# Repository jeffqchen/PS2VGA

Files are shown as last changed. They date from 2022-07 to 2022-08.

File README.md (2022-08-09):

# PS2VGA

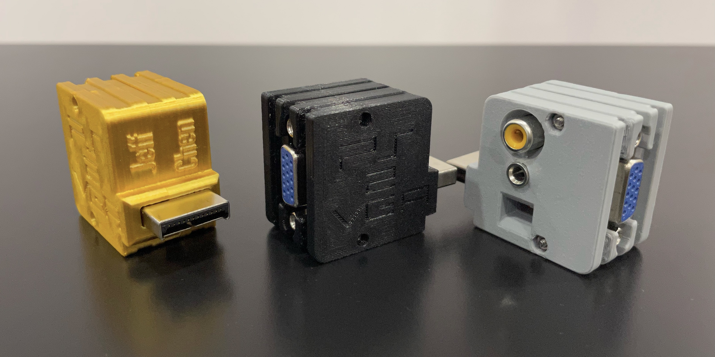
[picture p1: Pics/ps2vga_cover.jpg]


This is an RGB+CSync video and stereo audio analogue output dongle, with a VGA port, a 3.5mm jack and an RCA jack, for the entire PlayStation family. It is a member from my [Console VGA Dongle Series](https://github.com/jeffqchen/Console-VGA-Dongle-Series).

Please refer to the **[Project Wiki](https://github.com/jeffqchen/PS2VGA/wiki)** regarding technical details, parts and building guide.

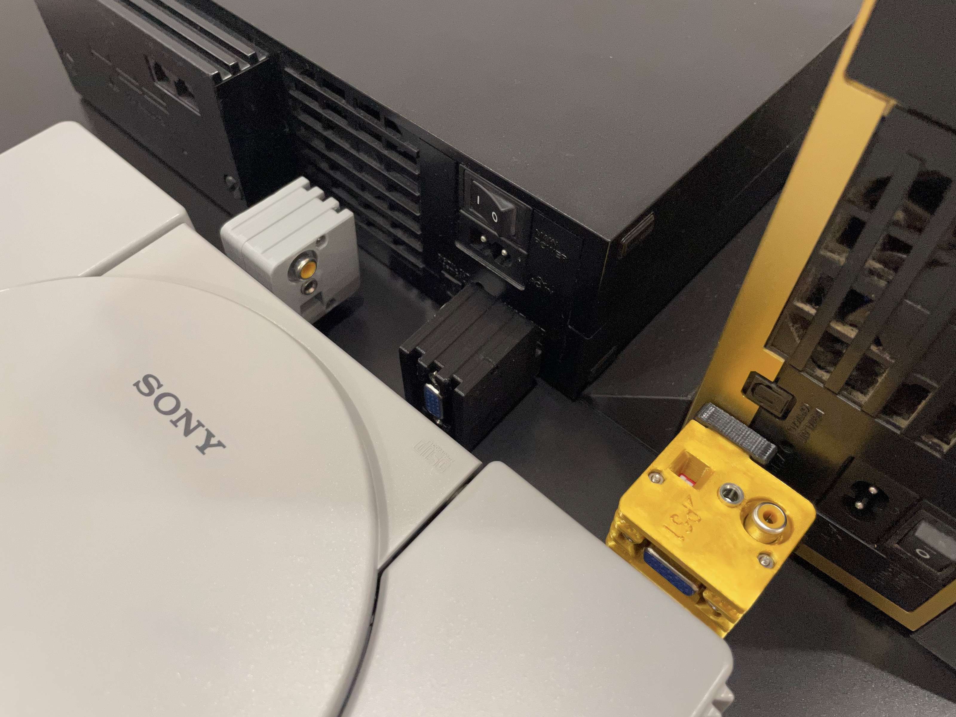
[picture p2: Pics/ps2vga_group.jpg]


---------
## Special Thanks

- Mike Chi of [RetroTINK](https://www.retrotink.com) - [Twitter](https://twitter.com/retrotink2)

- Javier Rodas - [Twitter](https://twitter.com/JaviRodasG)

- Retro Gamer Stuff (Bad_Ad84) - [Twitter](https://twitter.com/RetroGamerStuff)

--------
Shield: [][cc-by-sa]

This work is licensed under a
[Creative Commons Attribution-ShareAlike 4.0 International License][cc-by-sa].

[][cc-by-sa]

[cc-by-sa]: http://creativecommons.org/licenses/by-sa/4.0/
[cc-by-sa-image]: https://licensebuttons.net/l/by-sa/4.0/88x31.png
[cc-by-sa-shield]: https://img.shields.io/badge/License-CC%20BY--SA%204.0-lightgrey.svg

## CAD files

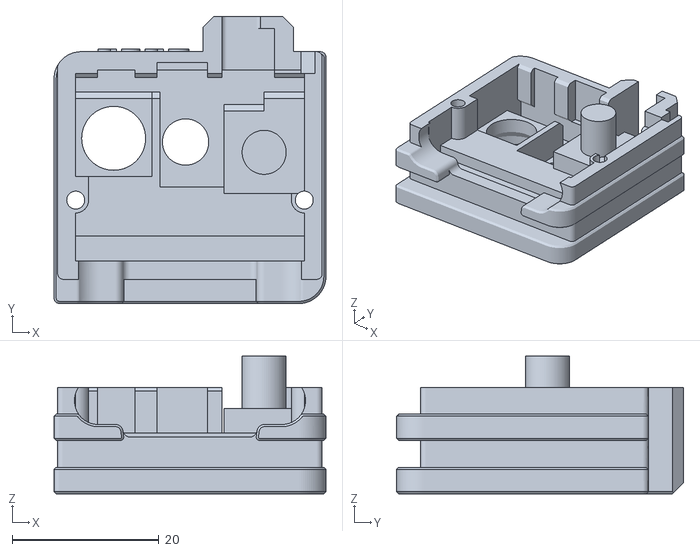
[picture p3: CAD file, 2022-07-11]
3D Print/Shell 2 PS1.stl
37.0 x 39.1 x 18.8

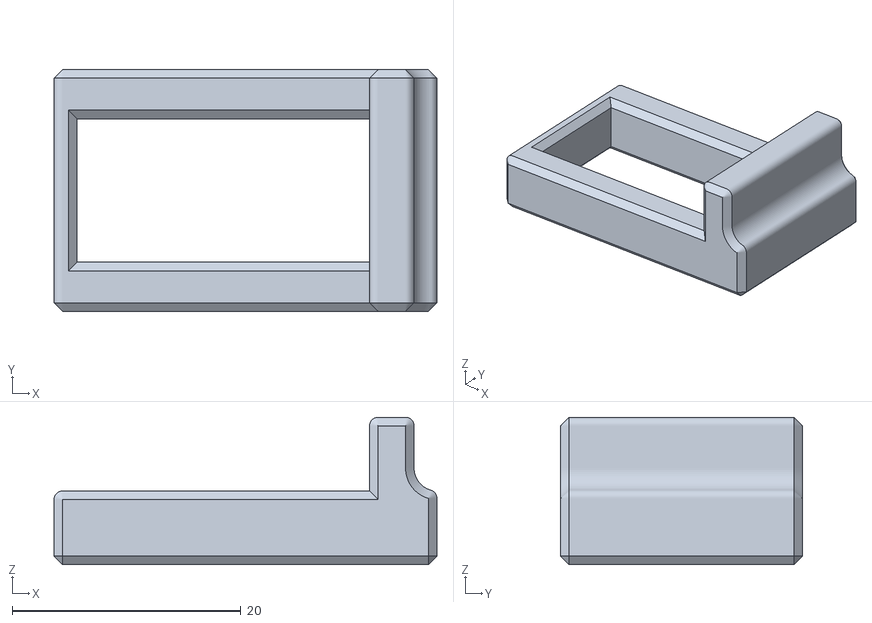
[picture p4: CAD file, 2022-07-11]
3D Print/Vertical Support Ring.stl
33.5 x 21.2 x 12.9

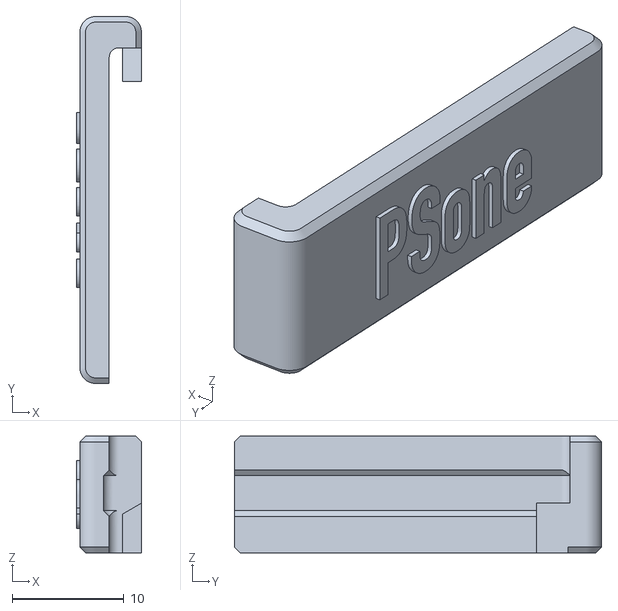
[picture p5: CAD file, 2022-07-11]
3D Print/HA - PSone.stl
5.80 x 32.8 x 10.4

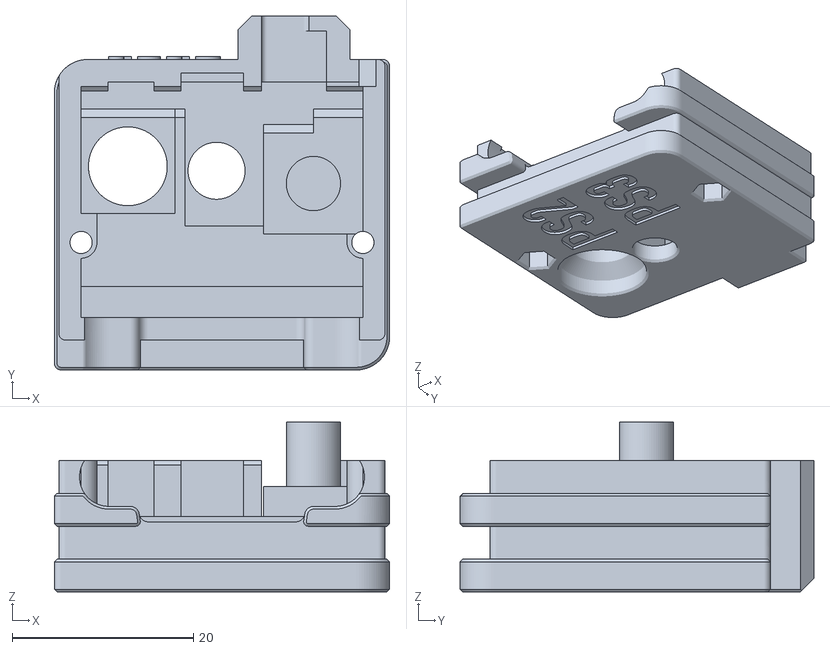
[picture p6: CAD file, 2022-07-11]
3D Print/Shell 2 PS2&3.stl
37.0 x 39.1 x 18.8

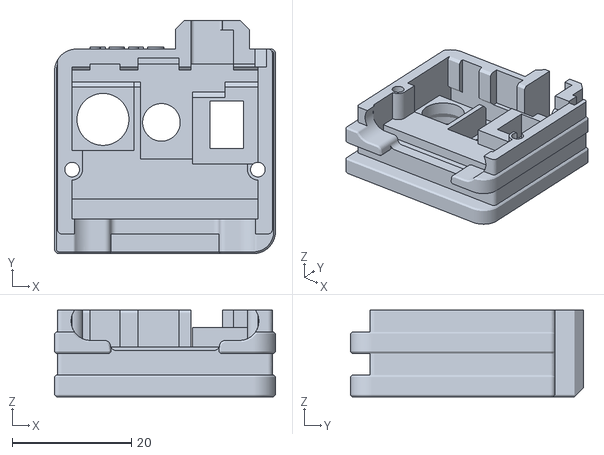
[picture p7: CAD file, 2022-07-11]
3D Print/Shell 2.stl
37.0 x 39.1 x 14.5

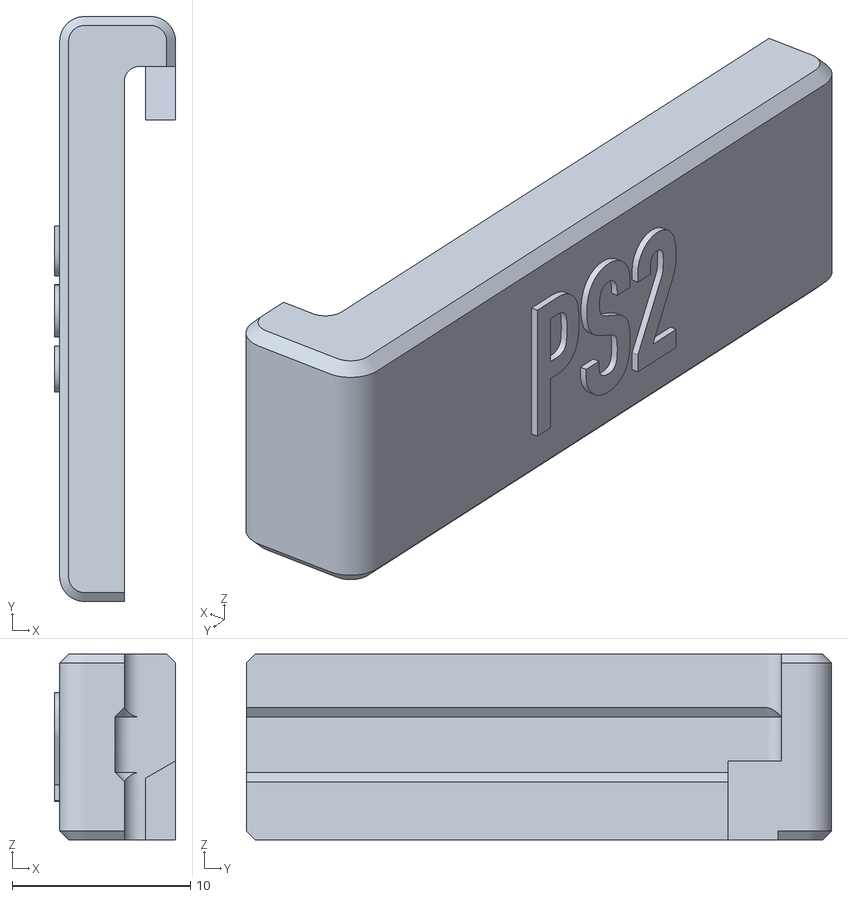
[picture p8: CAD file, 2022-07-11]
3D Print/HA - PS2.stl
6.80 x 32.8 x 10.4

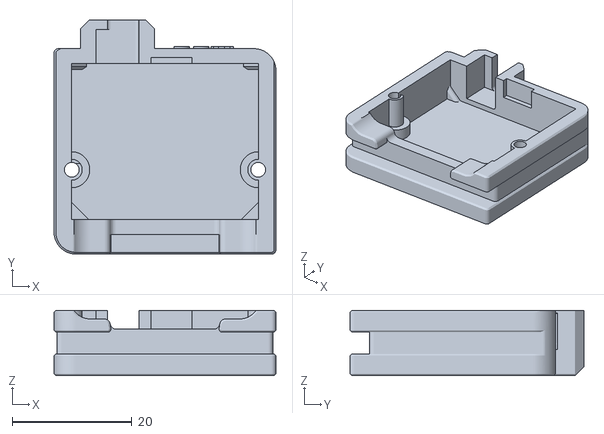
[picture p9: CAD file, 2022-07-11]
3D Print/Shell 1.stl
37.1 x 39.1 x 10.9

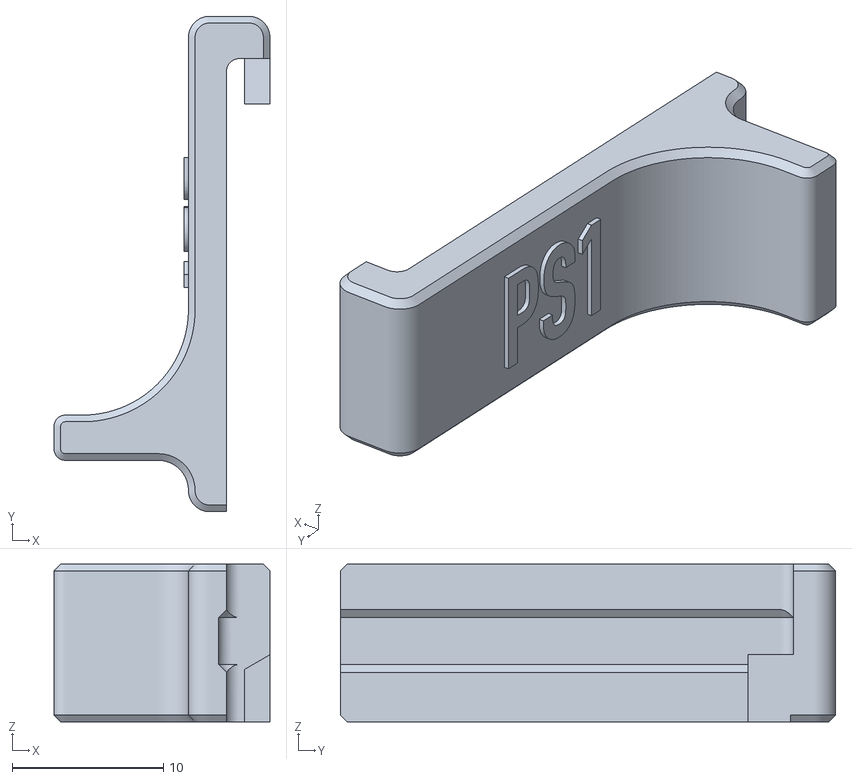
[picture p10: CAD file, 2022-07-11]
3D Print/HA - PS1.stl
14.3 x 32.8 x 10.4

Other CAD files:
3D Print/HA - PS2 Slim 1.stl

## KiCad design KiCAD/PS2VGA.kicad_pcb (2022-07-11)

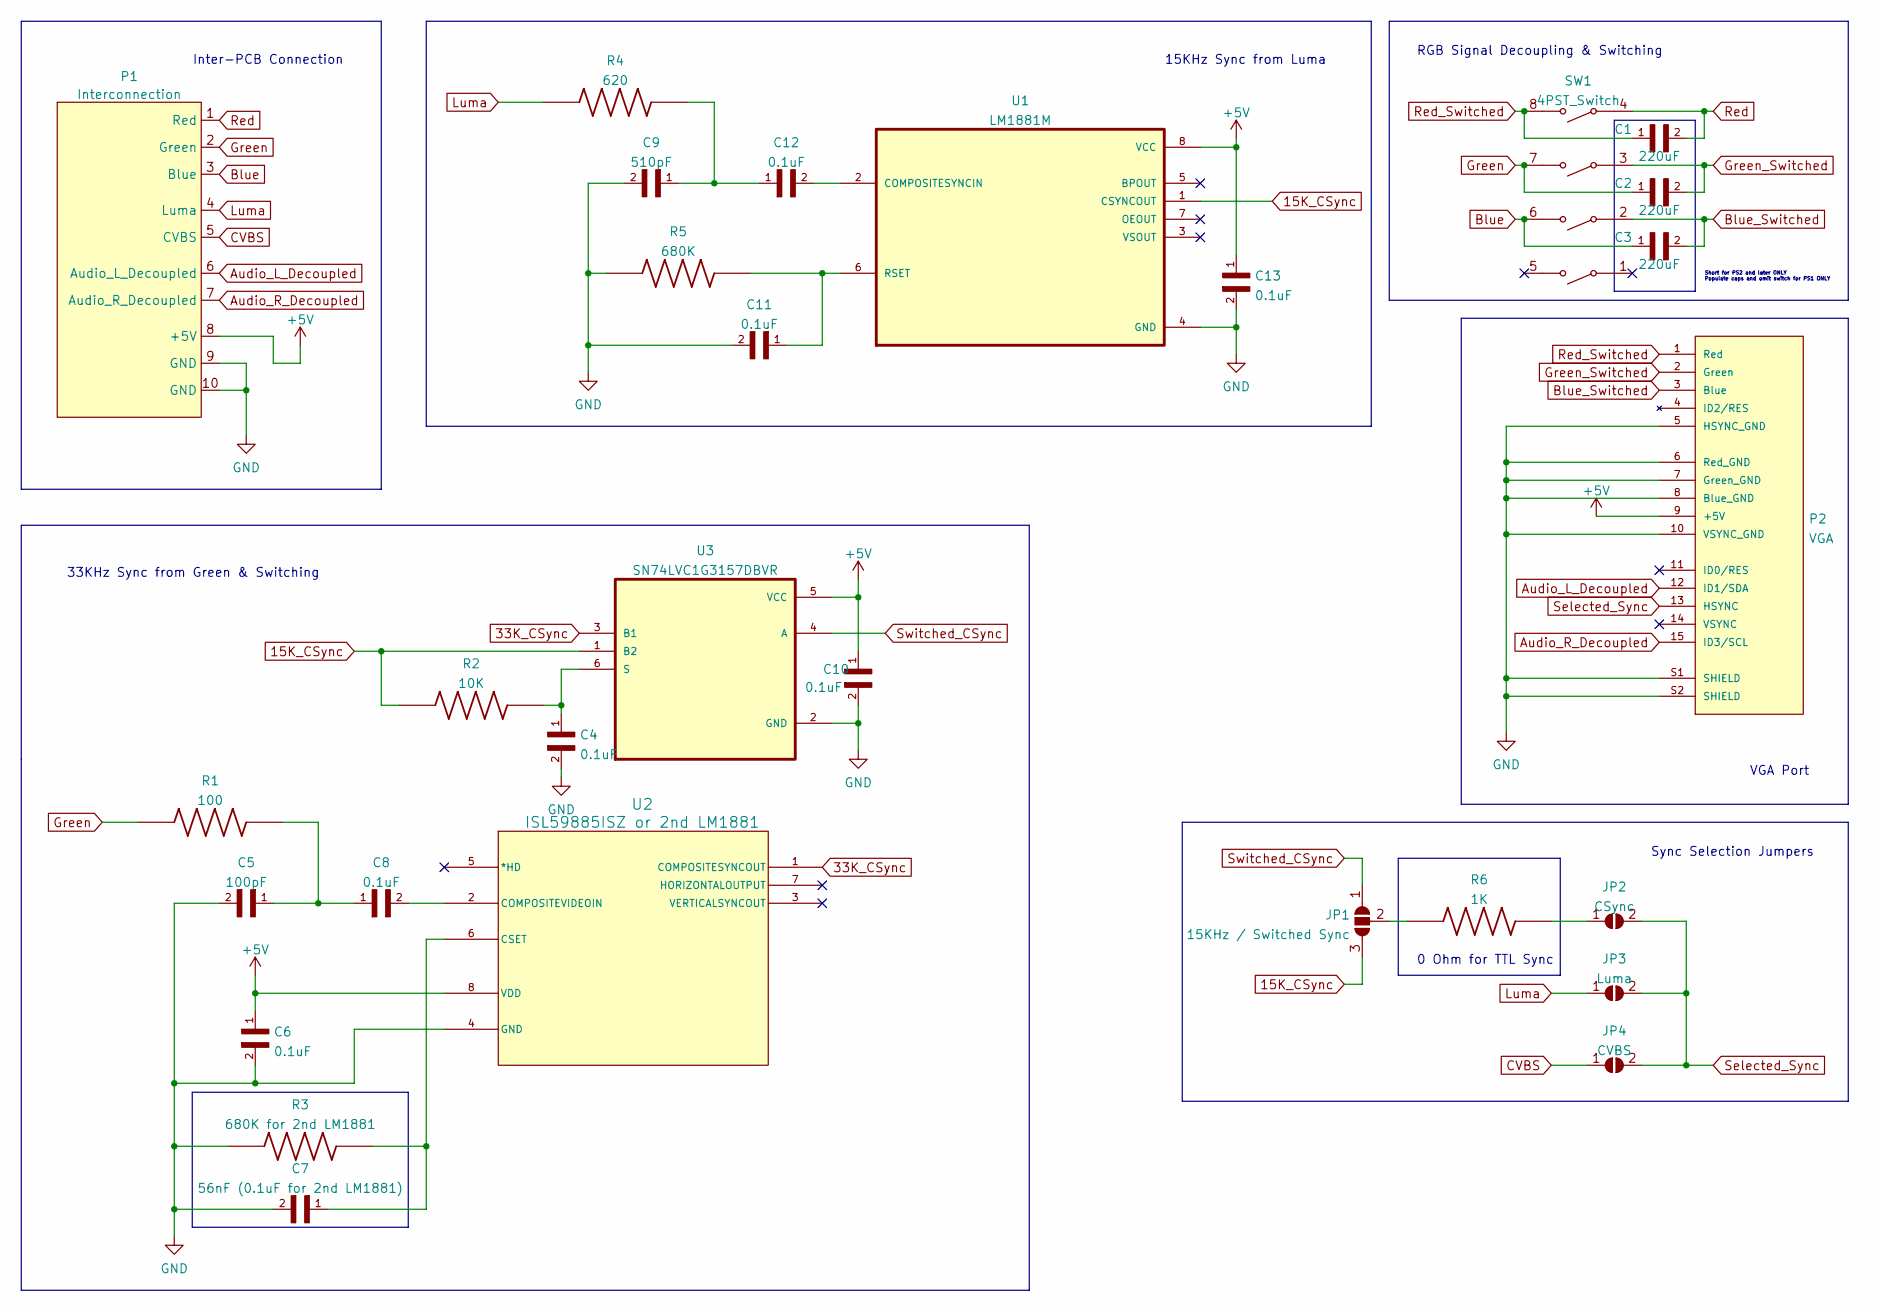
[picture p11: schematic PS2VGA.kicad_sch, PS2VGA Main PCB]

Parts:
C1, C2, C3: 220uF; C_1206_3216Metric
C4, C6, C8, C10, C11, C12, C13: 0.1uF; C_0603_1608Metric
C5: 100pF; C_0603_1608Metric
C7: 56nF (0.1uF for 2nd LM1881); C_0603_1608Metric
C9: 510pF; C_0603_1608Metric
JP1: 15KHz / Switched Sync; SolderJumper-3_P1.3mm_Open_RoundedPad1.0x1.5mm
JP2: CSync; SolderJumper-2_P1.3mm_Open_RoundedPad1.0x1.5mm
JP3: Luma; SolderJumper-2_P1.3mm_Open_RoundedPad1.0x1.5mm
JP4: CVBS; SolderJumper-2_P1.3mm_Open_RoundedPad1.0x1.5mm
P1: Interconnection
P2: VGA; VGA_female_rightangle_slim
R1: 100; R_0603_1608Metric
R2: 10K; R_0603_1608Metric
R3: 680K for 2nd LM1881; R_0603_1608Metric
R4: 620; R_0603_1608Metric
R5: 680K; R_0603_1608Metric
R6: 1K; R_0603_1608Metric
SW1: 4PST_Switch; 4PST Switch
U1: LM1881M; LM1881
U2: ISL59885ISZ or 2nd LM1881; ISL59885ISZ-ND
U3: SN74LVC1G3157DBVR

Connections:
15K_CSync: JP1.3 (B), R2.1, U1.1 (CSYNCOUT), U3.1 (B2); also elsewhere on the board
33K_CSync: U2.1 (COMPOSITESYNCOUT), U3.3 (B1)
+5V: C6.1, C10.1, C13.1, P1.8 (+5V), P2.9 (+5V), U1.8 (VCC), U2.8 (VDD), U3.5 (VCC); also elsewhere on the board
Audio_L_Decoupled: P1.6 (Audio_L_Decoupled), P2.12 (ID1/SDA)
Audio_R_Decoupled: P1.7 (Audio_R_Decoupled), P2.15 (ID3/SCL)
Blue: C3.1, P1.3 (Blue), SW1.6
Blue_Switched: C3.2, P2.3 (Blue), SW1.2
CVBS: JP4.1 (A), P1.5 (CVBS)
GND: C4.2, C5.2, C6.2, C7.2, C9.2, C10.2, C11.2, C13.2, P1.9 (GND), P1.10 (GND), P2.5 (HSYNC_GND), P2.6 (Red_GND), P2.7 (Green_GND), P2.8 (Blue_GND), P2.10 (VSYNC_GND), P2.S1 (SHIELD), P2.S2 (SHIELD), R3.1, R5.1, U1.4 (GND), U2.4 (GND), U3.2 (GND); also elsewhere on the board
Green: C2.1, P1.2 (Green), R1.1, SW1.7
Green_Switched: C2.2, P2.2 (Green), SW1.3
Luma: JP3.1 (A), P1.4 (Luma), R4.1
unnamed: C4.1, R2.2, U3.6 (S)
unnamed: C5.1, C8.1, R1.2
unnamed: C7.1, R3.2, U2.6 (CSET)
unnamed: C8.2, U2.2 (COMPOSITEVIDEOIN)
unnamed 16: C11.1, R5.2, U1.6 (RSET); also elsewhere on the board
unnamed: C9.1, C12.1, R4.2
unnamed 18: C12.2, U1.2 (COMPOSITESYNCIN); also elsewhere on the board
unnamed: JP1.2 (C), R6.1
unnamed: JP2.1 (A), R6.2
Red: C1.2, P1.1 (Red), SW1.4
Red_Switched: C1.1, P2.1 (Red), SW1.8
Selected_Sync: JP2.2 (B), JP3.2 (B), JP4.2 (B), P2.13 (HSYNC)
Switched_CSync: JP1.1 (A), U3.4 (A)

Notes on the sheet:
RGB Signal Decoupling & Switching
33KHz Sync from Green & Switching
0 Ohm for TTL Sync
Inter-PCB Connection
VGA Port
Short for PS2 and later ONLY Populate caps and omit switch for PS1 ONLY
15KHz Sync from Luma
Sync Selection Jumpers

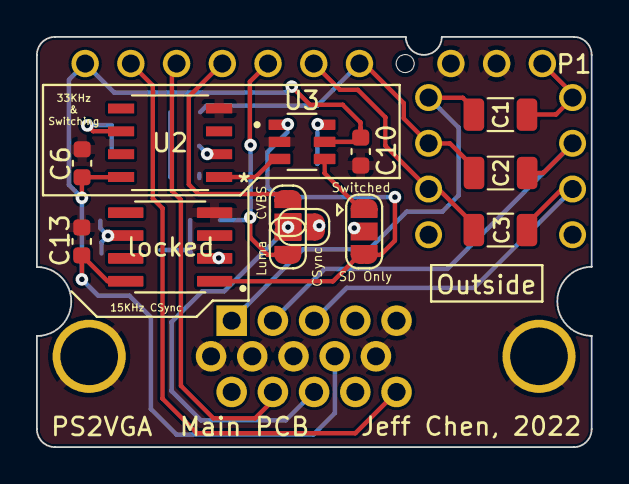
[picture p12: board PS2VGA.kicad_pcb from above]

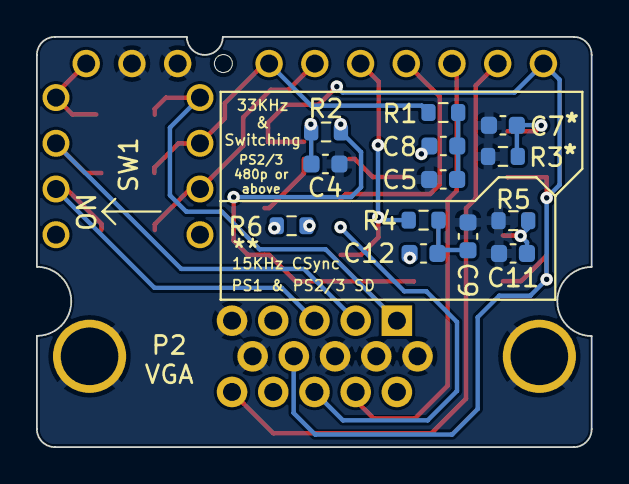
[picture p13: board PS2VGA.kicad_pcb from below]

Board: 2 copper layers, 30.8 x 22.8 mm, 29 parts (15 on the bottom side), 25 nets.

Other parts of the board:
locked: LM1881M; LM1881

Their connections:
15K_CSync: locked.1 (CSYNCOUT); also elsewhere on the board
+5V: locked.8 (VCC); also elsewhere on the board
GND: locked.4 (GND); also elsewhere on the board
unnamed 16: locked.6 (RSET); also elsewhere on the board
unnamed 18: locked.2 (COMPOSITESYNCIN); also elsewhere on the board

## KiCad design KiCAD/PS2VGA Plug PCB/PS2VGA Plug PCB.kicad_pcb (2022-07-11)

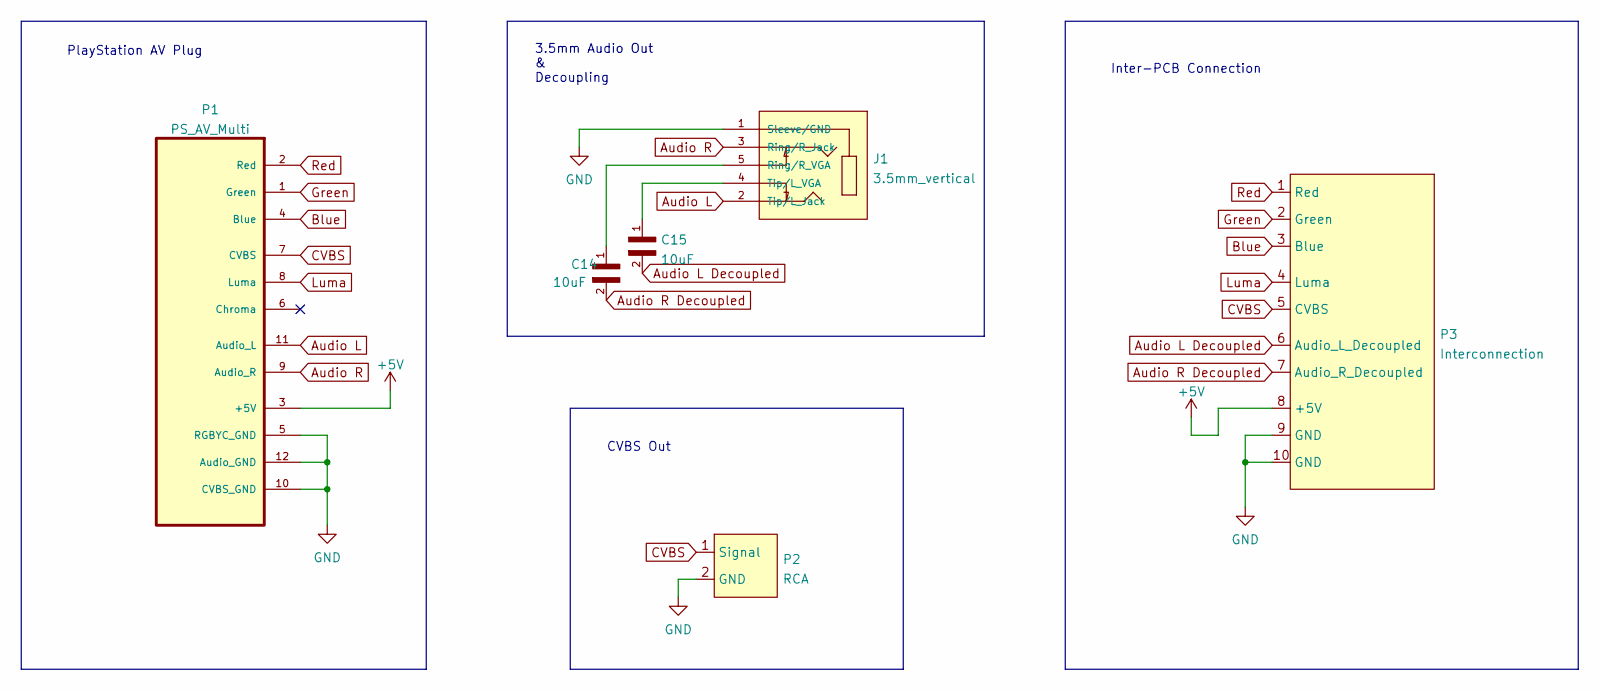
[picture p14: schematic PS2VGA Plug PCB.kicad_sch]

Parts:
C14, C15: 10uF; C_0603_1608Metric
J1: 3.5mm_vertical; PARTREV 1.01
P1: PS_AV_Multi
P2: RCA
P3: Interconnection

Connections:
+5V: P1.3 (+5V), P3.8 (+5V)
Audio L: J1.2 (Tip/L_Jack), P1.11 (Audio_L)
Audio L Decoupled: C15.2, P3.6 (Audio_L_Decoupled)
Audio R: J1.3 (Ring/R_Jack), P1.9 (Audio_R)
Audio R Decoupled: C14.2, P3.7 (Audio_R_Decoupled)
Blue: P1.4 (Blue), P3.3 (Blue)
CVBS: P1.7 (CVBS), P2.1 (Signal), P3.5 (CVBS)
GND: J1.1 (Sleeve/GND), P1.5 (RGBYC_GND), P1.10 (CVBS_GND), P1.12 (Audio_GND), P2.2 (GND), P3.9 (GND), P3.10 (GND)
Green: P1.1 (Green), P3.2 (Green)
Luma: P1.8 (Luma), P3.4 (Luma)
unnamed: C14.1, J1.5 (Ring/R_VGA)
unnamed: C15.1, J1.4 (Tip/L_VGA)
Red: P1.2 (Red), P3.1 (Red)

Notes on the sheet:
CVBS Out
Inter-PCB Connection
PlayStation AV Plug
3.5mm Audio Out & Decoupling

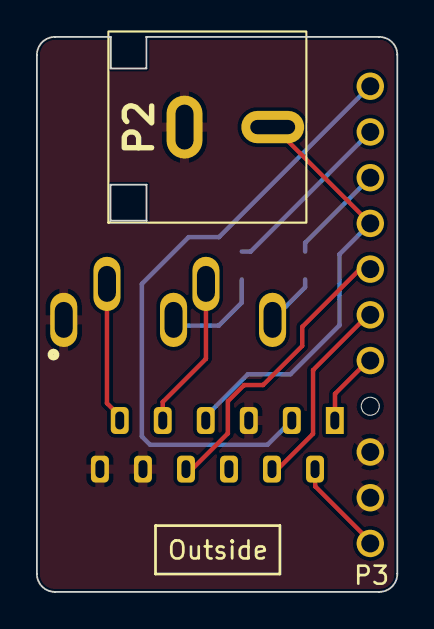
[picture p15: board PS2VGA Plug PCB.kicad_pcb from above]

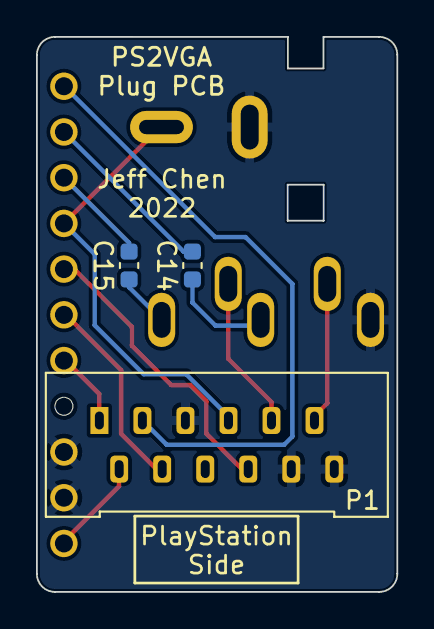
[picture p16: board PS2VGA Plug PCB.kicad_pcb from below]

Board: 2 copper layers, 20.0 x 30.8 mm, 6 parts (3 on the bottom side), 13 nets.

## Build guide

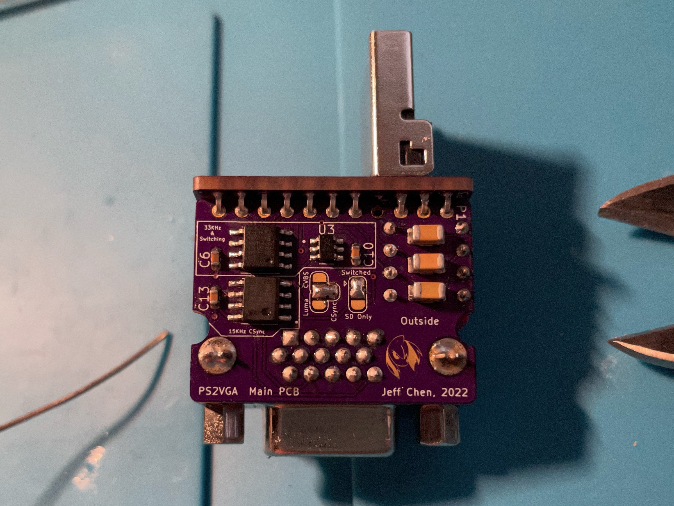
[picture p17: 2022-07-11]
Pics/assembly_final_04.jpg

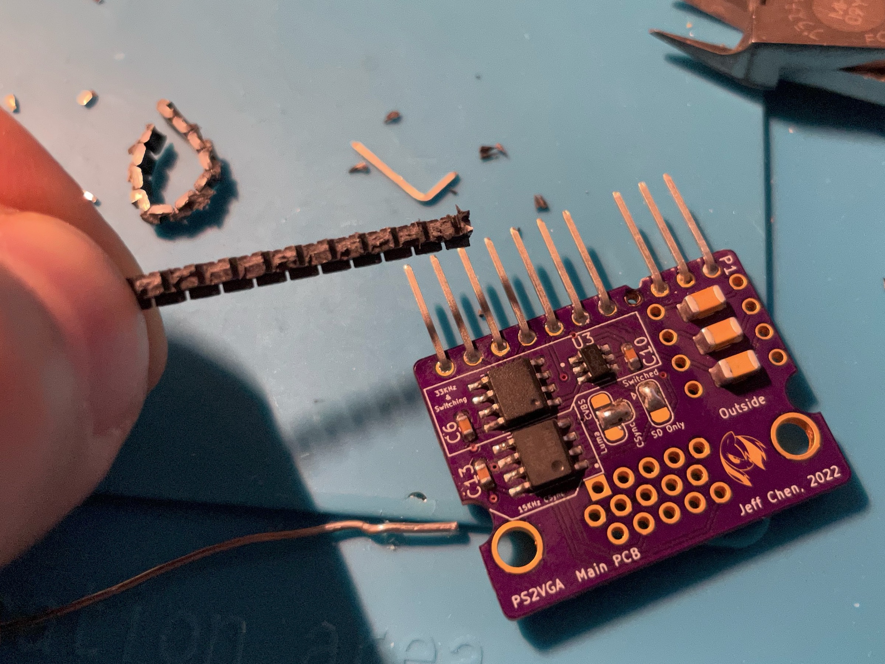
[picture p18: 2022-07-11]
Pics/assembly_pins_09.jpg

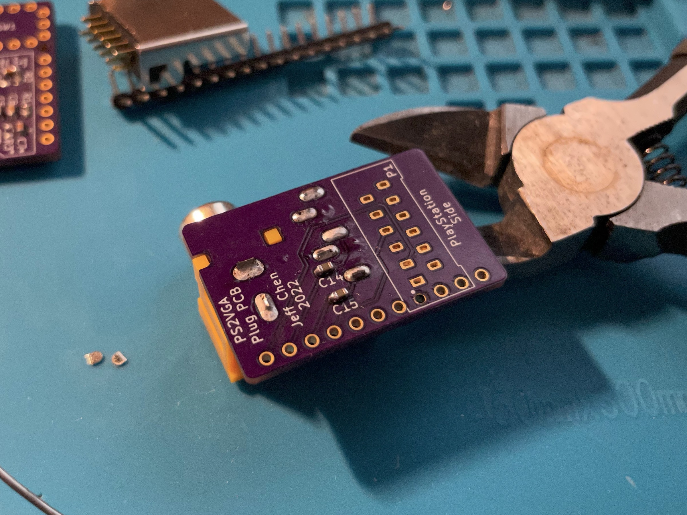
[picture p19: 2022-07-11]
Pics/assembly_thd_03.jpg

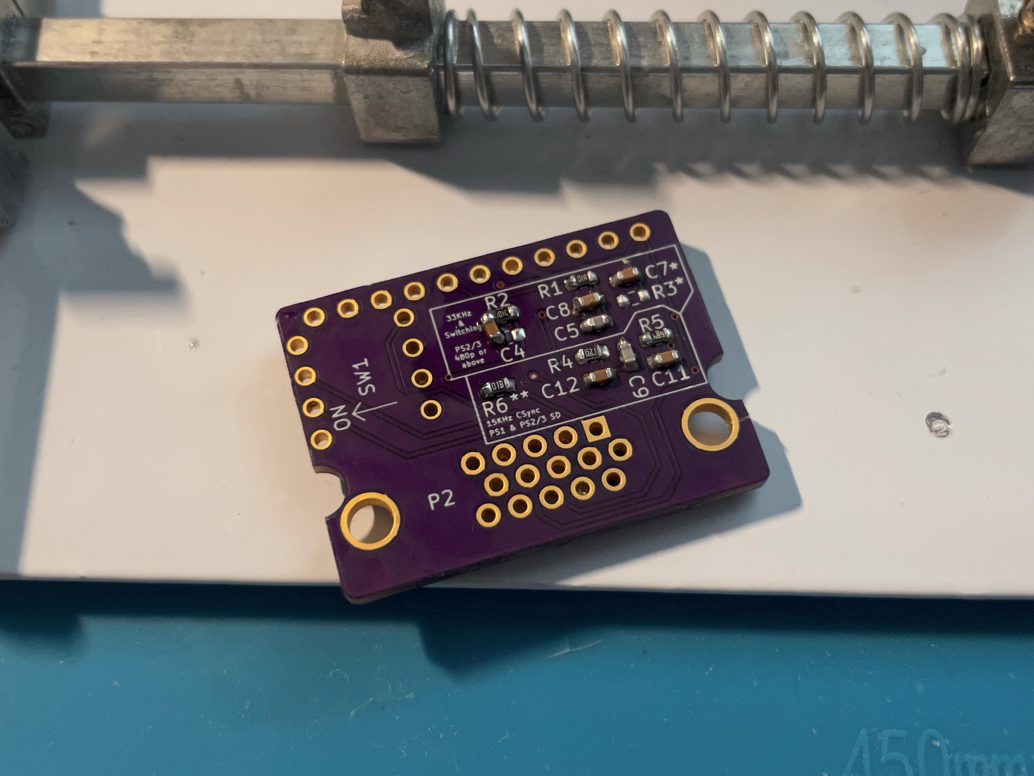
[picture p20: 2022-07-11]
Pics/assembly_smd_02.jpg

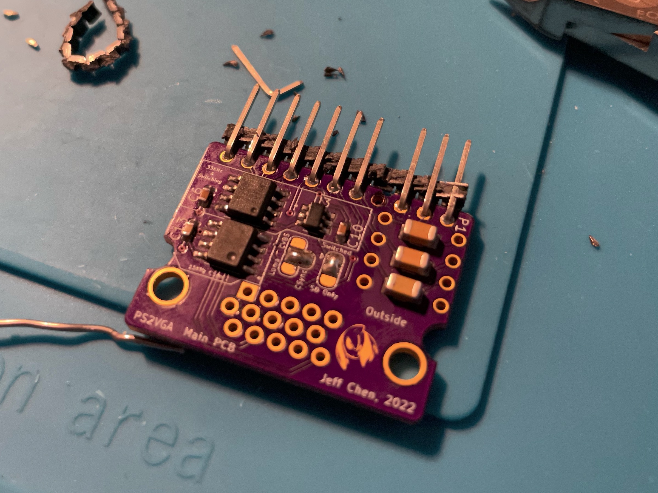
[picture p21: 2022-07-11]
Pics/assembly_pins_08.jpg

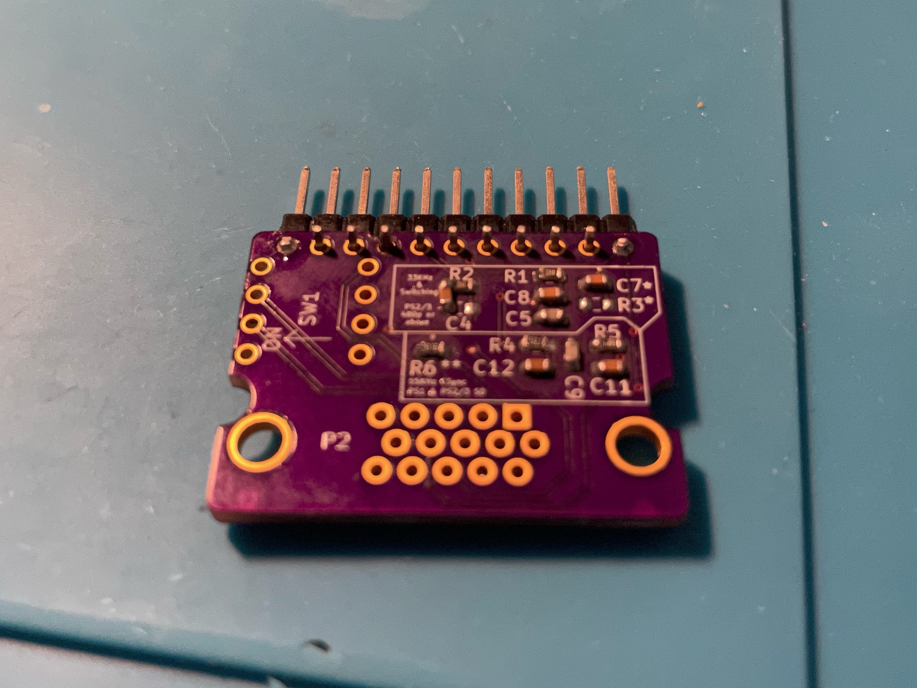
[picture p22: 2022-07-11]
Pics/assembly_pins_04.jpg

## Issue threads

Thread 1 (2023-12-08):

change sync-splitter to a single ISL59885 to support all modes

kfix, 2023-12-08:
the >=480p build spec requires a second LM1881 (U2) and a switch:
https://github.com/jeffqchen/PS2VGA/wiki/3.-Parts-&-Configurations#b-up-to-480p-ps23-only

and the HD build spec needs a ISL59885ISZ (U2) and a switch:
https://github.com/jeffqchen/PS2VGA/wiki/3.-Parts-&-Configurations#a-up-to-1080p-ps23-only

perhaps using the LMH1980 would allow a 1-chip solution to accept all resolutions without a switch?
https://www.ti.com/lit/an/snla097a/snla097a.pdf?ts=1701993779002

kfix, 2023-12-08:
I might try this with my build, just an electro-ignoramus so likely to get it wrong

kfix, 2023-12-08:
the ISL59885 seems to be another contender. available in the same SOIC-8 package unlike the 1980

kfix, 2023-12-08:
well, huh, the HD splitter is the fancy one. so why can't it do it all?

jeffqchen, 2023-12-09:
The PS2 outputs Luma only in 240p/480i mode. In 480p or higher it outputs SoG instead, and Luma is turned off. It's out of my league to do sync detection at the moment of the design.

Also the LM1881 is one order of magnitude cheaper than the fancy ISL chip. Having one sitting exclusively on the low resolution side doesn't jack up the cost by a lot. It's the fancy one that's overly expensive and not needed by everyone.

kfix, 2023-12-09:
doh, I forgot about it cutting out like that! thanks for the clarification.

the ISL is sourcing the green line and the 1881 on the luma. so when the PS2 RGB changes to RGsB (480p+), the ISL's HD pin goes high and the connected switch flips the csync output's source over to it. ingenious!

I'll be building one with both, thanks for putting up your designs and excellent instructions!

jeffqchen, 2023-12-09:
You are welcome!

jeffqchen, 2023-12-09:
And I remember now. If I relied on that ~HD signal, I would HAVE to have that ISL chip for switching, even for 480p. I wanted to allow using 2 of 1881 for up to 480p, and an LPF on the 15K CSync signal was enough to flip that switch.

Closed 2023-12-09.

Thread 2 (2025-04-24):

C9: 510pF / 6.3V

sansthesis, 2025-04-24:
I'm new to soldering and I was going to learn how to do thing while making VGA cables for all of my consoles to feed into my SVS and RT4K.

I've been able to find all of the caps I need for this project and the other consoles you support on Mouser or Digikey except for the 510pF / 6.3V one on C9.  I want to use csync for all of the cables because that's what the SVS claims to support, as well as the Extron MVX.

Secondly, why does the SNES2VGA have a 470 Ohm resister on R1 for csync but the PS2VGA does not?  Would I leave R1 unpopulated on the SNES2VGA if I want 5v TTL like you wrote for R6 resistor in the PS2VGA?

jeffqchen, 2025-04-24:
For capacitors, if the exact rating is not available, you can go up a few notches. It will still work.

For 5V TTL, simply use 0 Ohm resistors instead. The 470 Ohm choice is a middle value, which might be compatible with both consumer and professional devices. For proper values, it would be 1K Ohm for consumer, and 0 Ohm for professional.

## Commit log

2022-07-11 3D Print Models
    [HA - PS1.stl, HA - PS2 Slim 1.stl, HA - PS2.stl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]
2022-07-11 KiCAD files
    [PS2VGA Plug PCB-B_Cu.gbr, PS2VGA Plug PCB-B_Mask.gbr, PS2VGA Plug PCB-B_Paste.gbr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]
2022-07-11 Add PCB shot

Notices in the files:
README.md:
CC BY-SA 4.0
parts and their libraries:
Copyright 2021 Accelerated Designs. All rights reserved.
